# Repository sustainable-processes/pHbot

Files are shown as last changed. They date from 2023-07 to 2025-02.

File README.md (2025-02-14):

# pHbot: Self-Driven Robot for pH Adjustment of Viscous Formulations *via* Physics-informed-ML

We have developed the first-of-its-kind pH robot capable of small-scale batch titrations for viscous liquid formulations. The fully autonomous, closed-loop pH adjustment is driven by a "physics-informed" ML-driven titration algorithm. The work is detailed [here](doi.org/10.1002/cmtd.202300043) and this GitHub repository is part of the electronic supplementary information (ESI) released with the project. 

It should be noted that the pH robot can titrate a wide variety of systems, including aqueous solutions, but the focus has been presented on viscous formulations as the robot's design, along with mixing and cleaning protocols, were optimised to overcome the engineering challenge of titrating viscous systems. Furthermore, the titration algorithm can generally work with the use of any strong-strong or weak-strong acid/base pairs. A standalone [web application](https://aniketchitre-accelerate-titrations-titrationalgo-webapp-z383g2.streamlit.app) is also linked if you wish to use the hybrid ML algorithm to accelerate bench top pH adjustments, without additionally adopting the robotic technology. 

## Assembly of the pH Robot

Please find enclosed a bill of materials and assembly guide with the paper's SI. Several components need to be 3d-printed and their designs can be found under the `CAD_DesignFiles` directory. Please follow the `pHBotAssemblyGuide.pdf` to build the robot yourself.

## Operation of the pH Robot 

1. Clone the repo

```console
git clone https://github.com/sustainable-processes/pHbot.git
```

2. Create a virtual environment and install the dependencies

Firstly, follow the steps to create a virtualenv for your respective OS system ([Mac](https://sourabhbajaj.com/mac-setup/Python/virtualenv.html)/[Windows](https://mothergeo-py.readthedocs.io/en/latest/development/how-to/venv-win.html)). Then install the required package dependencies for this project.

```console
pip install -r requirements.txt
```
It is recommended to use Python version 3.9 or 3.10 to avoid package installation conflicts.

3. Open and run `pHRobot_Operation.ipynb`

### Description of the Code Files

The Jupyter Notebook is a completely commented-out self-contained file to guide the reader to operate the pH robot. The notebook is divided into sections: 

0. Importing Packages and Hardware Objects

The pH robot operates using an object-oriented framework and calls upon the various class object definitions under the `hardware` directory:

* `PlatformMovement.py` controls the robot's movement in a cartesian geometry.
* `C3000_SyringePumpsv2.py` controls high-precision TriContinent C-series syringe pumps to dose acid/base.
* `Sentron_pHmeter.py` logs data from the Sentron MicroFET pH probe.
* `Stirrer_WashPump.py` controls two pumps (inlet/outlet) to the robot's washing station, as well as the impeller for mixing the analyte.

1. Initialising Hardware and Protocol Functions

i) Initaites communication with the hardware objects;
ii) Defines fixed co-ordinates for the sample jars;
iii) Defines functions to be called within the titration algorithm for autonomous execution of the robot's unit operations.

2. Titration Algorithm

The "physics-informed" ML titration algorithm is defined. Please see the manuscript (to be published) with this work for details.

4. Platform Operation and Results

Finally, the pH robot can be called to titrate a single sample at a time, or a batch of samples (up to 12). `pHRobot_Operation.ipynb` has been provided with some sample output to show you what successful execution of a batch of pH adjustments on the robot should look like. 

## Titration Algorithm Web App 

A separate web application (https://aniketchitre-accelerate-titrations-titrationalgo-webapp-z383g2.streamlit.app) has been developed and hosted on Streamlit to accelerate traditional pH adjustment workflows. This is the same algorithm as run on the pH robot and found in the Jupyter Notebook, except it's for those interested parties that may wish to adopt the algorithm, without necessarily reproducing the pH platform we have presented. Please note if the web application has gone to sleep, you may simply "wake up" the app from your end. 

## Issues 

Submit an issue or email [Aniket Chitre](ac2349@cantab.ac.uk) for any software-related issues (e.g., titration algorithm/web app, control of the pH robot) and [Jayce Cheng](jayce_cheng@imre.a-star.edu.sg) for any hardware related questions (e.g., assembly of the pH robot). 

## Citing

If you find this project useful, we encourage you to: 
* Star this repository &#11088;
* Cite our paper (https://doi.org/10.1002/cmtd.202300043)

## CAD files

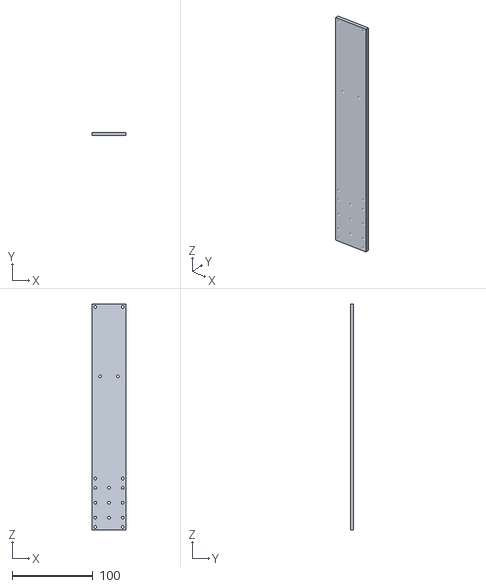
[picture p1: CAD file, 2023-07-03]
CAD_DesignFiles/PETG Probe assembly frame.stl
42.0 x 4.00 x 280.0

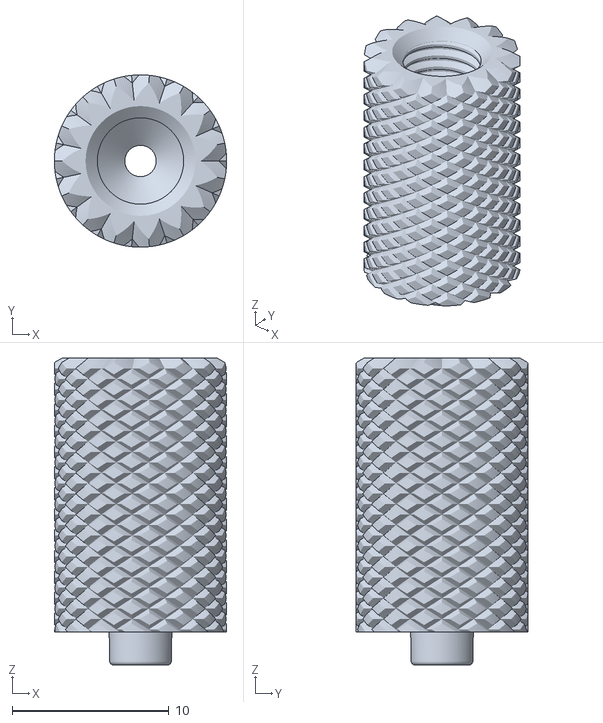
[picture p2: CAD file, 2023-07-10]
CAD_DesignFiles/1-16 microfluidic male luer lock adapter.stl
11.0 x 11.0 x 19.6

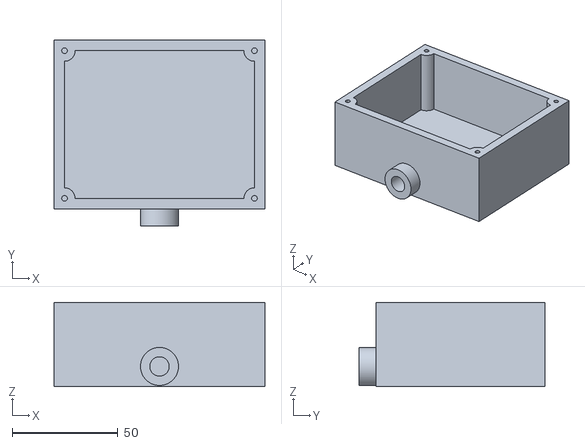
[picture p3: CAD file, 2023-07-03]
CAD_DesignFiles/Resin Wash station base.stl
100.0 x 88.0 x 40.0

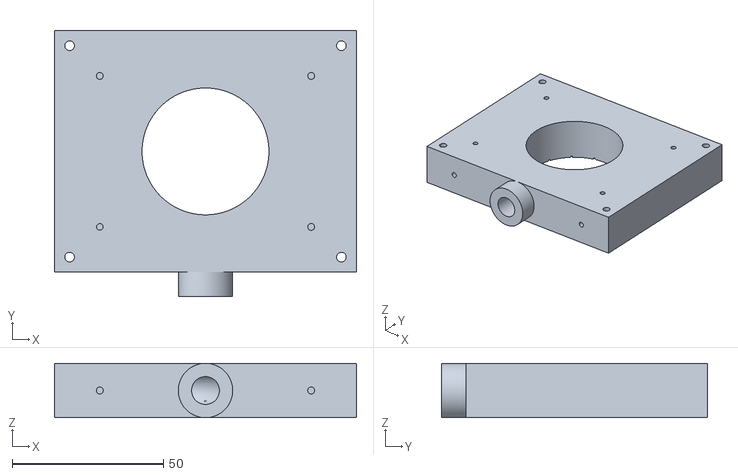
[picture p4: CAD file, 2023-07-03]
CAD_DesignFiles/Resin Wash station top.stl
100.0 x 88.0 x 18.0

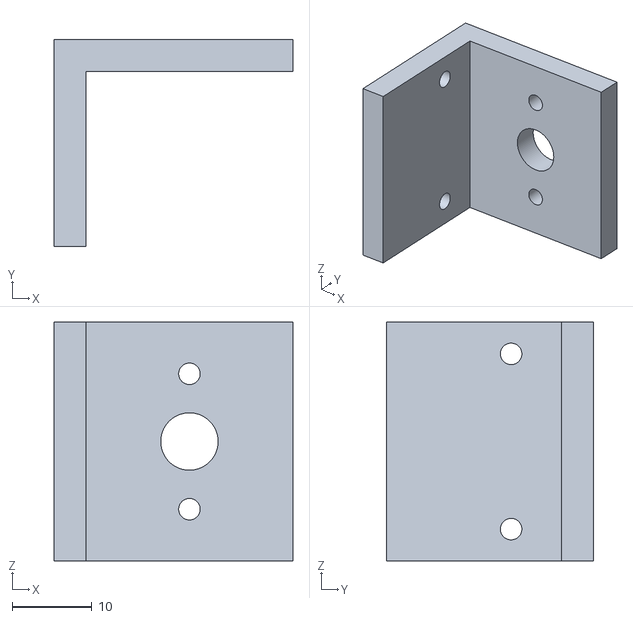
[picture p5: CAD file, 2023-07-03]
CAD_DesignFiles/PETG Motor mount.stl
30.0 x 26.0 x 30.0

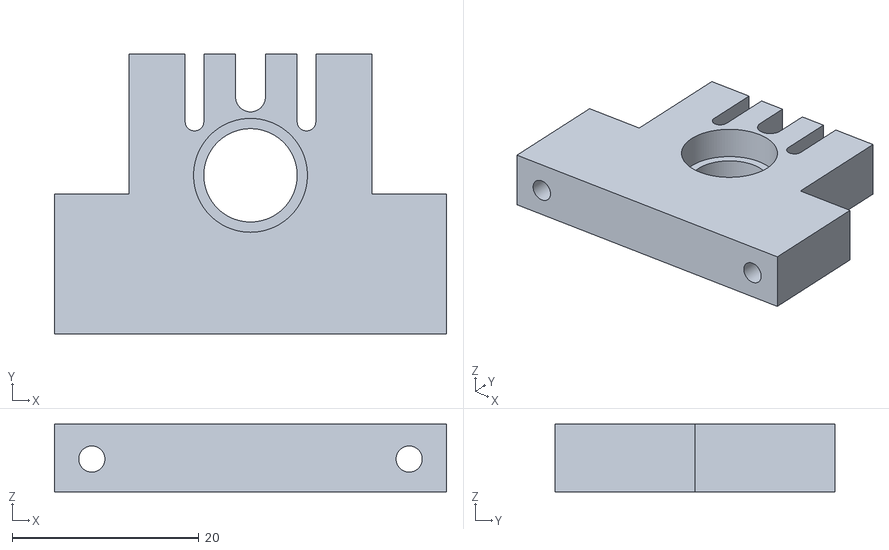
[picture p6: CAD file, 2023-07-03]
CAD_DesignFiles/PETG Bearing mount.stl
42.0 x 30.0 x 7.28

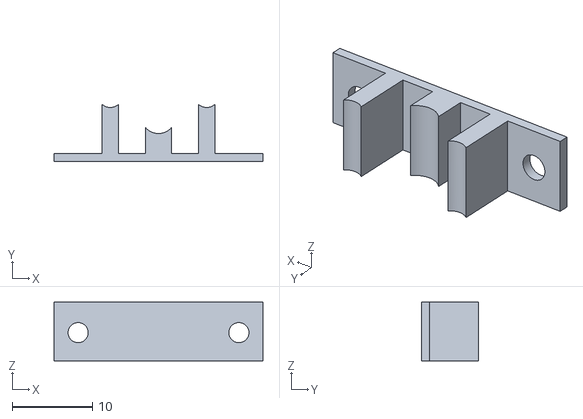
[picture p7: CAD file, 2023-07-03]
CAD_DesignFiles/PETG Clip.stl
26.0 x 7.14 x 7.28

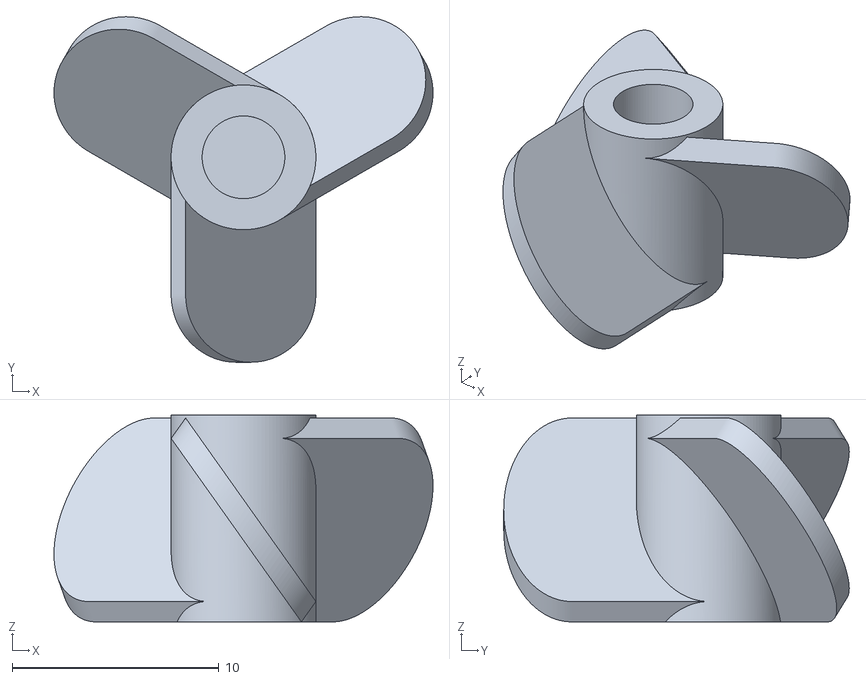
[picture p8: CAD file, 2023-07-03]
CAD_DesignFiles/PETG Propeller.stl
18.3 x 16.7 x 10.00

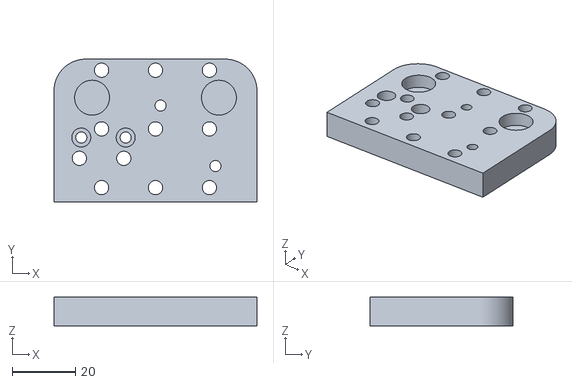
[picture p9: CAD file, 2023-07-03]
CAD_DesignFiles/PETG Ender adapter plate.stl
64.0 x 45.0 x 9.00

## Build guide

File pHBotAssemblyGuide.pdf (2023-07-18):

# pHBOT

### 1 GENERAL INFORMATION

DESIGNER
Aniket Chitre
Jayce Cheng

INSTITUTION
Cambridge Centre for Advanced Research and Education in Singapore Institute of Materials Research and Engineering, A*STAR, Singapore

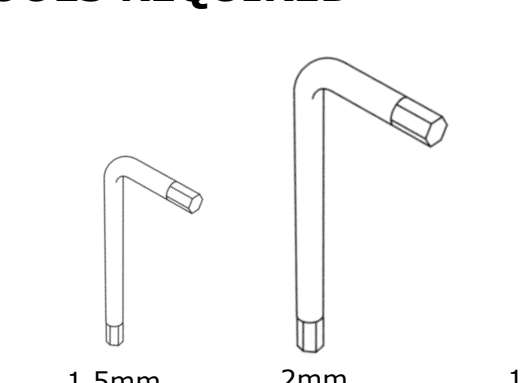
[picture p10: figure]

1.5mm | 2mm | 1/8” NPT | 1/4” NPT | 235oC

### 2 DESCRIPTION

This is the assembly guide for the pHBOT: self-driving titration robot.

*Labware not included
*Wiring and tubing not shown

### 3 RESOURCES

- Access to FDM 3D printing
- Access to SLA, DLP or equivalent resin 3D printing
- Basic soldering

### 4 TOOLS REQUIRED

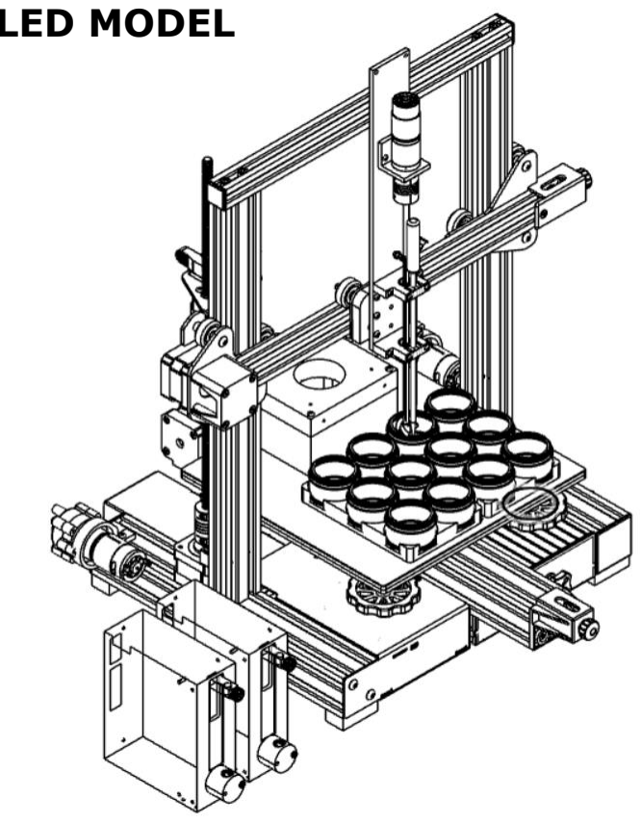
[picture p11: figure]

### 5 ASSEMBLED MODEL

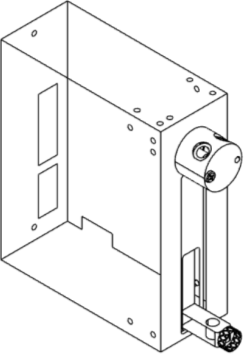
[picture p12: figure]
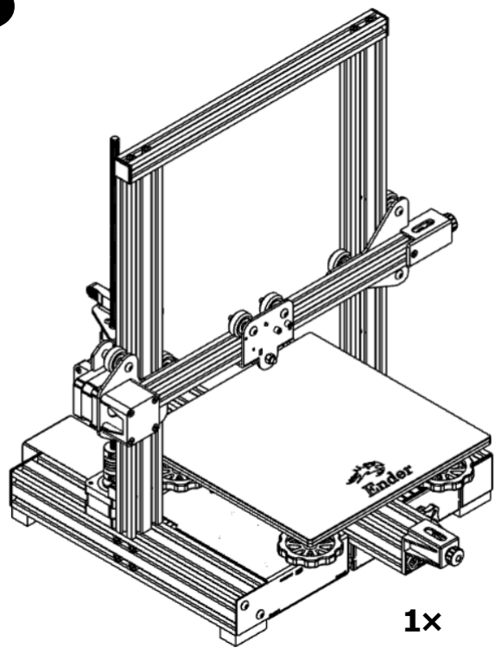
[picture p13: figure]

Creality Ender 3 Pro/V2, extruder assembly removed

2

×

TriContinent C3000

1

×

Sentron SI series pH probe

1

×

Stainless steel optical axis Ø5mm L 200mm

Stainless steel needle, 100mm, Luer-Lock

1

×

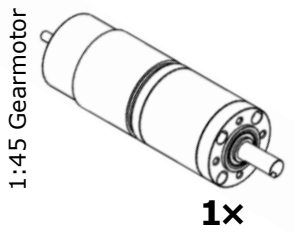
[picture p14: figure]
1:45 Gearmotor

M4-M5

coupling

1

×

Needle

bearing

2

×

4

×

M2.5 ×4 Button

4

×

M2.5 ×6Button

4

×

M2.5 ×18 Button

8

×

M3 ×8 Button

4

×

M3 ×12 CSK

Arduino Nano V3

1

×

DC motor driver

2

×

Diaphragm pump

2

×

4

×

M3 × 25 Button

1

×

1

×

1/4” NPT – Hose 3/8"

1/8” NPT – Hose 1/4”

$

2

×

2020 M3
T-nut

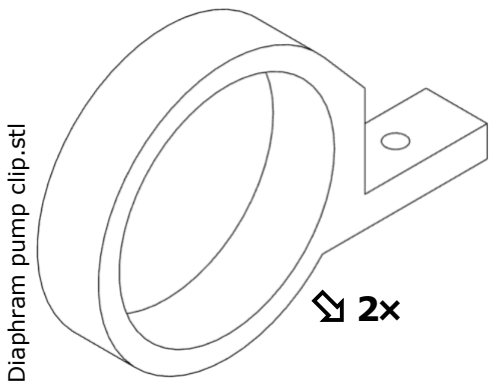
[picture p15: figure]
Diaphram pump clip.stl
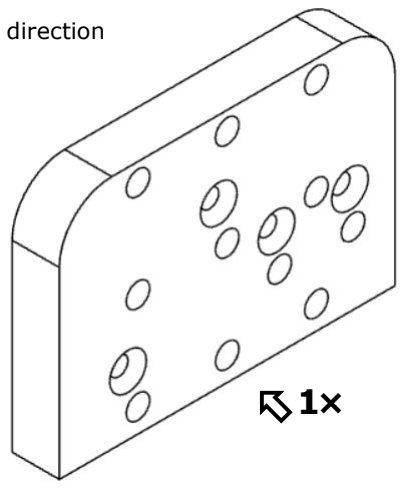
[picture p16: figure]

Ender 3 adapter plate.stl

Probe assembly frame.stl

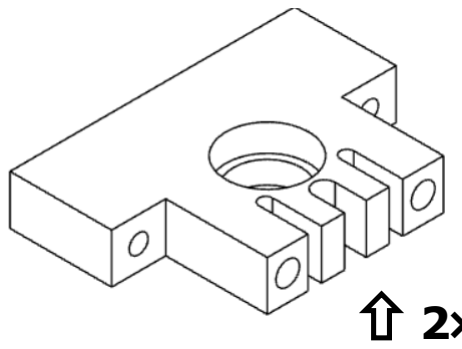
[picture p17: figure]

×

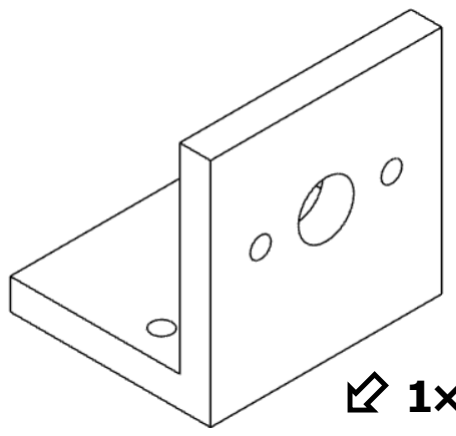
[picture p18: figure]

Bearing mount.stl

Clip.stl

Propeller.stl

2

×

1

×

2

×

×

Motor mount.stl

Print direction

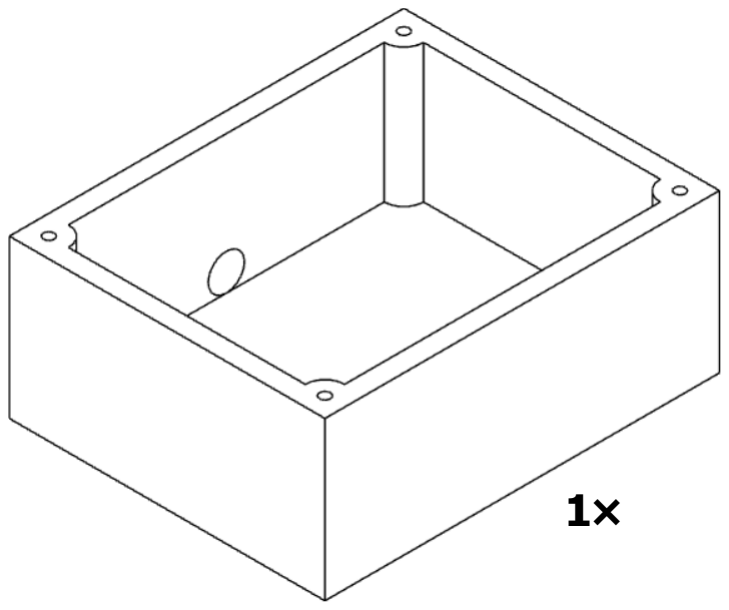
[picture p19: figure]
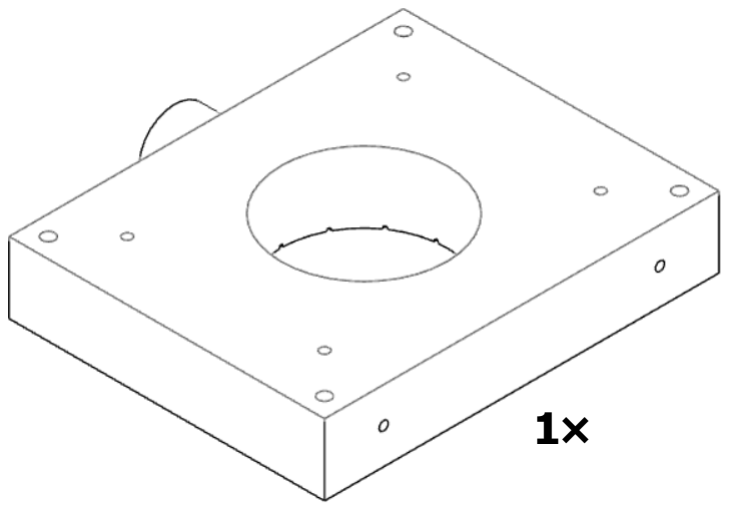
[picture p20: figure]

Wash station top.stl
Wash station base.stl

# 1 Tap

2

×

Luer lock adapter.stl

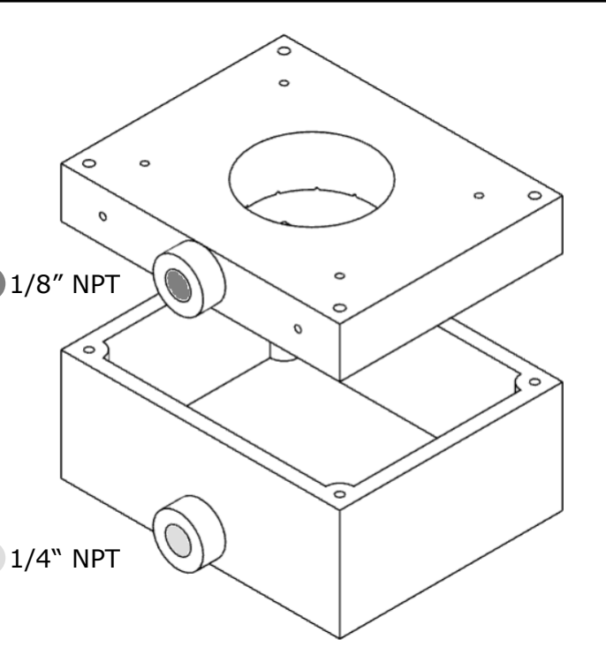
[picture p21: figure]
1/8” NPT; 1/4“ NPT

# 2 Heat Insert

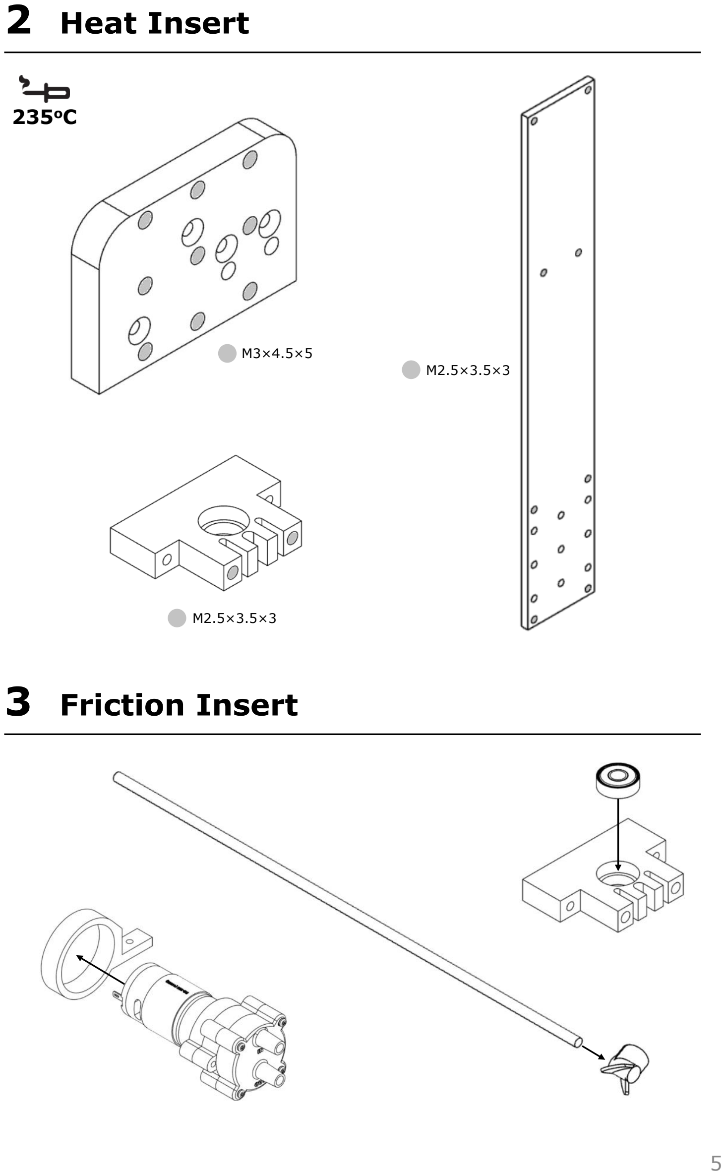
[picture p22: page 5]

235oC

M3×4.5×5

M2.5×3.5×3

M2.5×3.5×3

# 3 Friction Insert

# 4 Assembly

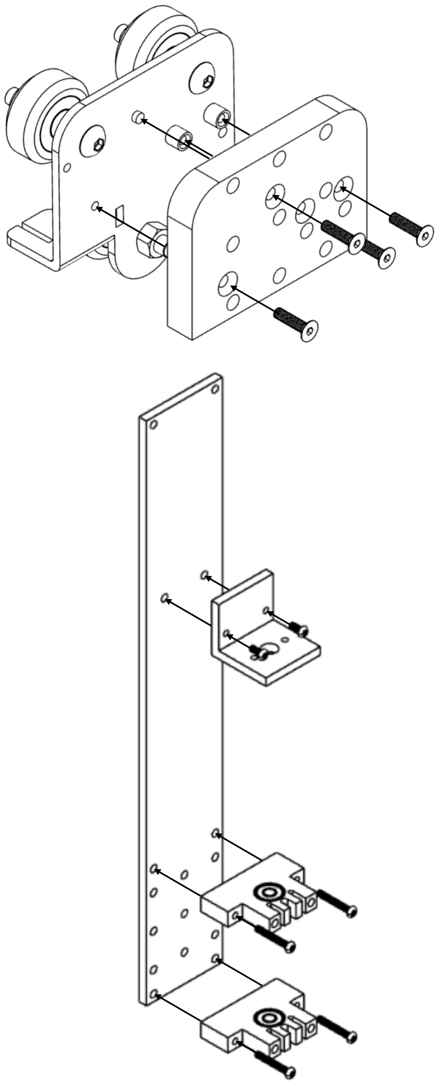
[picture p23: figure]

1

2

3 4

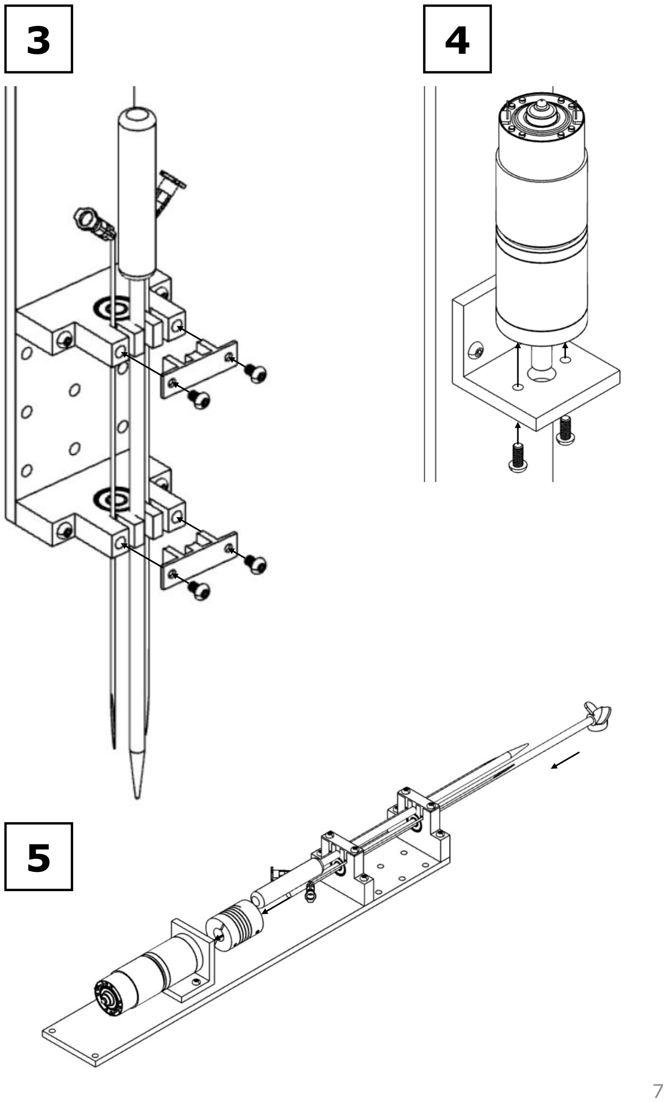
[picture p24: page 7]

5

6

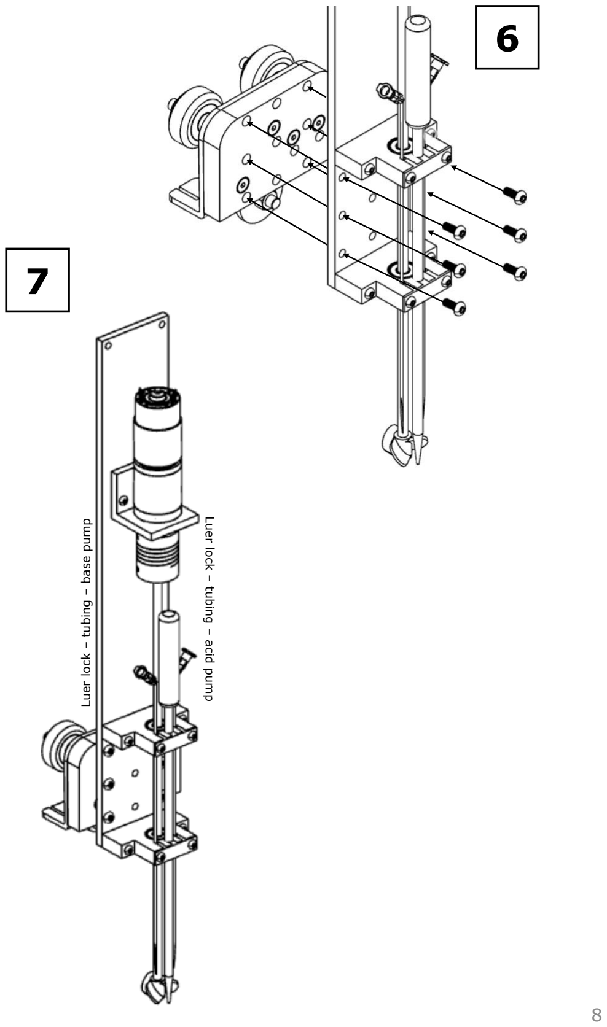
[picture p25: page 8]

Luer lock – tubing – base pump

Luer lock – tubing – acid pump

7

89

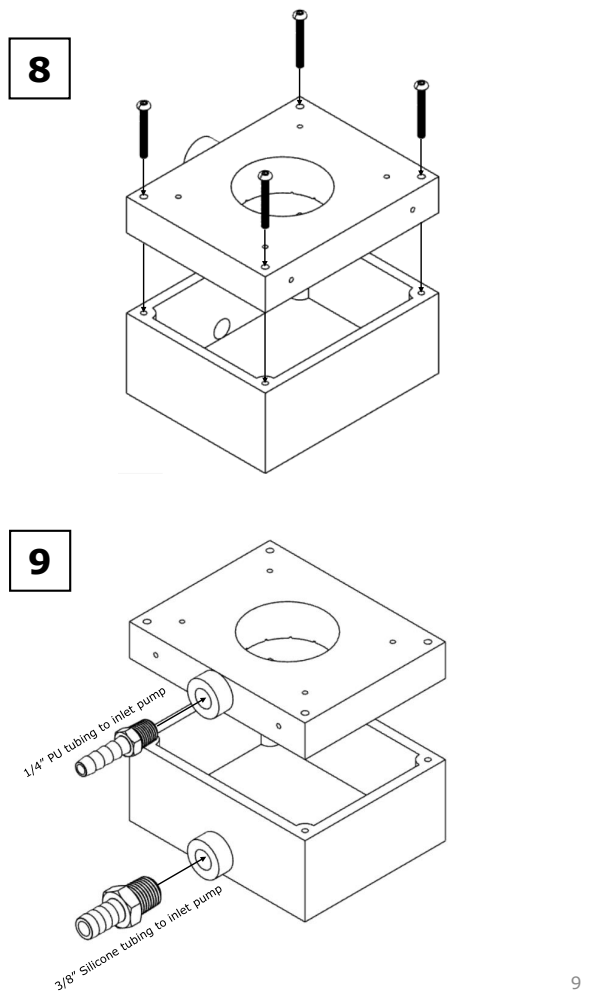
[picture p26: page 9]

10

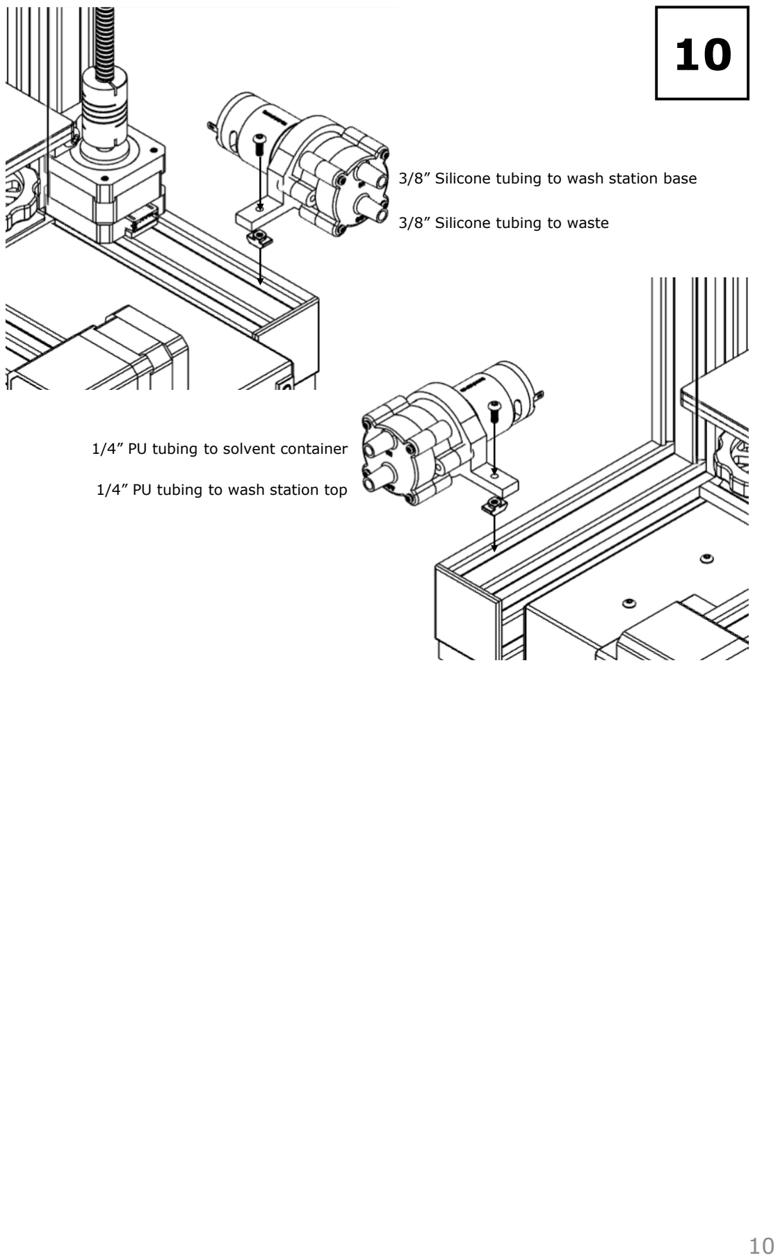
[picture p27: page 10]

3/8” Silicone tubing to waste

3/8” Silicone tubing to wash station base

1/4” PU tubing to solvent container

1/4” PU tubing to wash station top

11

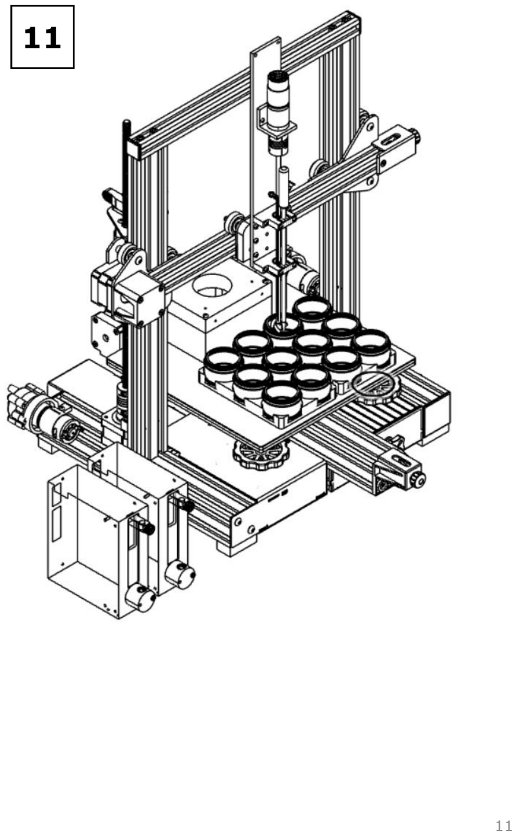
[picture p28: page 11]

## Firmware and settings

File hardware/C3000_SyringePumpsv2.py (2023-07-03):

"""
Class object to control the Tricontinent C-Series Syringe Pumps

Author: Aniket Chitre
Date: July 2022
"""

import serial
import time

# See configuration jumpers on manual pp.22
# J2: 1, 5 installed, J9: none installed on all pumps except last - 1,2 installed on final pump
# Followed RS-232 cabling diagram
# Pumps in series communicate over RS-485, hence no RS-485 termination jumpers on all but last pump


class C3000_pump:

    baud_rate = 9600    # communications rate - set by J2 jumper #4
    to = 1              # timeout
    pause_time = 2    # delay required between writing and reading to the serial object

    # Key strings for pump control
    beg_char = '/'      # Start of command
    end_char = '\r'     # End of command
    run = 'R'           # Run. Execute the command string. Not required for certain classes of commands - e.g., reporting commands
    init_CW = 'Z'       # Initialise with CW configuration - sets valve output to the right - see diagram pp. 50
    # Pump initialises by default in the "N0" normal increment mode - full stroke = 3000 increments

    valve_to_input = 'I'
    valve_to_output = 'O'
    valve_to_bypass = 'B'

    # Plunger moves at a start velocity and accelerates to a "top velocity" and decelerates back down - motion controlled by driver automatically
    set_start_vel = 'v'     # power-up default = 900 increment/sec, range: 1 - 1000
    set_top_vel = 'V'       # power-up default = 1400 increment/sec, range: 1 - 6000
    set_ramp_slopes = 'L'   # see pp. 66 - default: 14 (= 35,000 increment/s^2) - I think <L10> will be suitable (25,000 increment/s^2)
    # n.b. power-up defaults to fast - cause cavitation when using 1/16" tubing

    absolute_pos = 'A'  # range: 0 - 3000 - volume dispensed = displacement of plunger
    rel_pos_down = 'P'  # aspirate
    rel_pos_up = 'D'  # dispense

    syringe_vol = 1000  # uL
    max_N = 3000  # max number of increments for C3000

    # default start-up status prior to pump connection or initialisation
    con_status  = False
    init_status = False
    dose_cmd    = ''

    def __init__(self, port, address):
        self.ser = None
        self.port = port
        self.address = address

    def connect(self):
        self.ser = serial.Serial(port=self.port, baudrate=self.baud_rate, timeout=self.to)
        self.__setattr__('con_status', True)
        self.ser.close()    # close the connection, so another pump can be opened over the same COM port
        return self.con_status

    # all method calls enclosed with the serial port being opened and closed on the first and penultimate lines
    # crucial to avoid conflicts on port access

    def initialise(self):
        self.ser.open()
        init_str = self.beg_char + self.address + self.init_CW + self.run + self.end_char
        init_byt = init_str.encode('utf-8')
        self.ser.write(init_byt)
        self.__setattr__('init_status', True)
        self.ser.close()
        return self.init_status

    def prime(self, prime_cycles):
        self.ser.open()
        # g opens the loop - G closes the loop and prime_cycles is the num_iter around this loop
        # g IA3000 (set to input valve and fill the syringe fully) OA0 (empty syringe completely) G
        prime_str = self.beg_char + self.address + self.init_CW + \
                    self.set_start_vel + '50' + self.set_top_vel + '200' + 'L1' + \
                    'g' + \
                    self.valve_to_input + self.absolute_pos + '3000' \
                    + self.valve_to_output + self.absolute_pos + '0' + \
                    'G' + prime_cycles + self.run + self.end_char
        prime_byt = prime_str.encode('utf-8')
        self.ser.write(prime_byt)
        # checks whether the pump is busy executing a command or idle and accordingly prints when priming is complete
        status_check_str = self.beg_char + self.address + 'Q' + self.end_char
        status_check_byt = status_check_str.encode('utf-8')
        pump_status = 'busy'    # default value, during the command call, the pump is busy
        while pump_status == 'busy':
            self.ser.write(status_check_byt)
            time.sleep(0.2)
            pump_check = str(self.ser.read_until('').decode('utf-8'))
            if pump_check[2] == '@':    # manual pp.90 shows 3rd character = @ if the pump is busy, or ` if it is free
                pass
            elif pump_check[2] == '`':
                pump_status = 'free'    # only break the while loop once the task is complete and pump is idle again
        self.ser.close()
        return print("Priming of pump complete")

    # Titrating 8 mL formulations, experiments have shown ~ 500 uL acid/base is required for the titration
    # 2.5 mL capacity of the syringes, shall be sufficient

    def dose(self, vol, start_vel, top_vel):
        self.ser.open()
        # checks the current absolute position of the syringe to determine whether it needs to be filled again before dispensing
        pos_check_str = self.beg_char + self.address + '?' + self.end_char
        pos_check_byt = pos_check_str.encode('utf-8')
        self.ser.write(pos_check_byt)
        time.sleep(self.pause_time)     # pause time important for the instrument to have time to write back to the computer
        raw_out = self.ser.read_until().decode('utf-8')
        abs_pos = int(raw_out.split('`')[1].split('\x03')[0])   # studied the outputted string and splitting it according to return position

        vol_per_N = self.syringe_vol / self.max_N   # technically the finest resolution of the syringe --> 2500/3000 = 0.8333 uL
        num_N = int(vol / vol_per_N)     # compute the increments for the screw to traverse to dispense the desired volume

        if abs_pos >= 0.8 * self.max_N:    # if the syringe is more than 75% full directly dispense the desired amount
            disp_str = self.beg_char + self.address + self.set_start_vel + str(start_vel) + self.set_top_vel + str(top_vel) + 'L1' + \
                       self.rel_pos_up + str(num_N) + self.run + self.end_char
            disp_byt = disp_str.encode('utf-8')
            self.ser.write(disp_byt)
            self.__setattr__('dose_cmd', disp_str)
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

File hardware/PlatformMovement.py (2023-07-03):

"""
Class object to control the Ender platform for cartesian movements of the pH robot.

Author: Leong Chang Jie
Date: June 2022
"""
import time
import numpy as np
import serial
import serial.tools.list_ports
from debugger import Debugger
debug = Debugger(show_logs=True)

# %% Serial / CNC
def display_ports():
    """
    Displays available ports.
    """
    ports = serial.tools.list_ports.comports()
    for port, desc, hwid in sorted(ports):
        print("{}: {} [{}]".format(port, desc, hwid))
    if len(ports) == 0:
        print("No ports detected!")
        print("Simulating platform...")
    return


class CNC(object):
    """
    Controller for cnc xyz-movements.
    - address: serial address of cnc Arduino
    """
    def __init__(self, address):
        self.address = address
        # self.cnc = self.connect_cnc(address)
        self.current_x = 0
        self.current_y = 0
        self.current_z = 0
        self.space_range = [(0,0,0), (0,0,0)]
        self.Z_safe = np.nan
        return

    def connect_cnc(self, address):
        """
        Establish serial connection to cnc controller.
        - address: port address

        Return: serial.Serial object
        """
        cnc = None
        try:
            cnc = serial.Serial(address, 115200, timeout=1) 
            cnc.close()
            cnc.open()

            # Start grbl 
            cnc.write(bytes("\r\n\r\n", 'utf-8'))
            time.sleep(2)
            cnc.flushInput()

            # Homing cycle
            cnc.write(bytes("$H\n", 'utf-8'))
            #print(cnc.readline())
            print("CNC ready")
        except:
            pass
        return cnc
    
    def to_position(self, coord, z_to_safe=True, print_statement= False):
        """
        Move cnc to absolute position in 3D
        - coord: (X, Y, Z) coordinates of target
        """

        if z_to_safe and self.current_z < self.Z_safe:
            try:
                self.cnc.write(bytes("G90\n", 'utf-8'))
                #print(self.cnc.readline())
                self.cnc.write(bytes(f"G0 Z{self.Z_safe}\n", 'utf-8'))
                #print(self.cnc.readline())
                self.cnc.write(bytes("G90\n", 'utf-8'))
                #print(self.cnc.readline())
            except:
                pass
            self.current_z = self.Z_safe
            if print_statement == True:
                print(f'{self.current_x}, {self.current_y}, {self.current_z}')

        x, y, z = coord
        z_first = True if self.current_z < z else False
        l_bound, u_bound = np.array(self.space_range)
        next_x = x
        next_y = y
        next_z = z
        next_pos = np.array([next_x, next_y, next_z])

        if all(np.greater_equal(next_pos, l_bound)) and all(np.less_equal(next_pos, u_bound)):
            pass
        else:
            print(f"Range limits reached! {self.space_range}")
            return

        positionXY = f'X{x}Y{y}'
        position_Z = f'Z{z}'
        moves = [position_Z, positionXY] if z_first else [positionXY, position_Z]
        try:
            self.cnc.write(bytes("G90\n", 'utf-8'))
            #print(self.cnc.readline())
            for move in moves:
                self.cnc.write(bytes(f"G1 {move} F20000\n", 'utf-8'))
                #print(self.cnc.readline())
            self.cnc.write(bytes("G90\n", 'utf-8'))
            #print(self.cnc.readline())
        except:
            pass

        self.current_x = next_x
        self.current_y = next_y
        self.current_z = next_z
        #print(f'{self.current_x}, {self.current_y}, {self.current_z}')
        return


class Ender(CNC):
    """
    XYZ controls for Ender platform.
    - address: serial address of cnc Arduino
    - space_range: range of motion of tool
    """
    def __init__(self, address, space_range=[(0,0,0), (220,220,250)], Z_safe=90):
        super().__init__(address)
        self.cnc = self.connect_cnc(address)
        self.space_range = space_range
        self.Z_safe = Z_safe
        self.home()
        return
    
    def connect_cnc(self, address):
        """
        Establish serial connection to cnc controller.
        - address: port address

        Return: serial.Serial object
        """
        cnc = None
        try:
            cnc = serial.Serial(address, 115200)
        except:
            pass
        return cnc

    def home(self):
        """
        Homing cycle for Ender platform
        """
        try:
            self.cnc.write(bytes("G90\n", 'utf-8'))
            #print(self.cnc.readline())
            self.cnc.write(bytes("G0 " + f"Z{self.Z_safe}" + "\n", 'utf-8'))
            #print(self.cnc.readline())
            self.cnc.write(bytes("G90\n", 'utf-8'))
            #print(self.cnc.readline())

            self.cnc.write(bytes("G28\n", 'utf-8'))

            self.cnc.write(bytes("G90\n", 'utf-8'))
            #print(self.cnc.readline())
            self.cnc.write(bytes("G0 " + f"Z{self.Z_safe}" + "\n", 'utf-8'))
            #print(self.cnc.readline())
            self.cnc.write(bytes("G90\n", 'utf-8'))
            #print(self.cnc.readline())
        except:
            pass
        self.current_x = 0
        self.current_y = 0
        self.current_z = self.Z_safe
        print(f'{self.current_x}, {self.current_y}, {self.current_z}')
        try:
            self.cnc.write(bytes("G1 F5000\n", 'utf-8'))
            #print(self.cnc.readline())
        except:
            pass
        return
